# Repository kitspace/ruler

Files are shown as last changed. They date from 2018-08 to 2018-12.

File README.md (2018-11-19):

# Kitspace PCB Ruler

A PCB design reference ruler made using Inkscape, [svg2shenzhen](https://github.com/badgeek/svg2shenzhen/) and KiCad (v5). It's up [on Kitspace](https://kitspace.org/boards/github.com/monostable/ruler/) of course. You can [buy it on Tindie](https://www.tindie.com/products/kasbah/kitspace-pcb-ruler-2/) while stocks last.

- You can use it as a ruler and as a reference for footprint sizes when working on a PCB design.
- The front is a functioning circuit if you populate it. The LEDs will light up if you connect it via USB and press the buttons.
- There are also pads for testing LED polarity.
- It's in a panel to show off two different ways to attach designs within a panel: mouse-bites and v-score. These are indicated on the back as well.

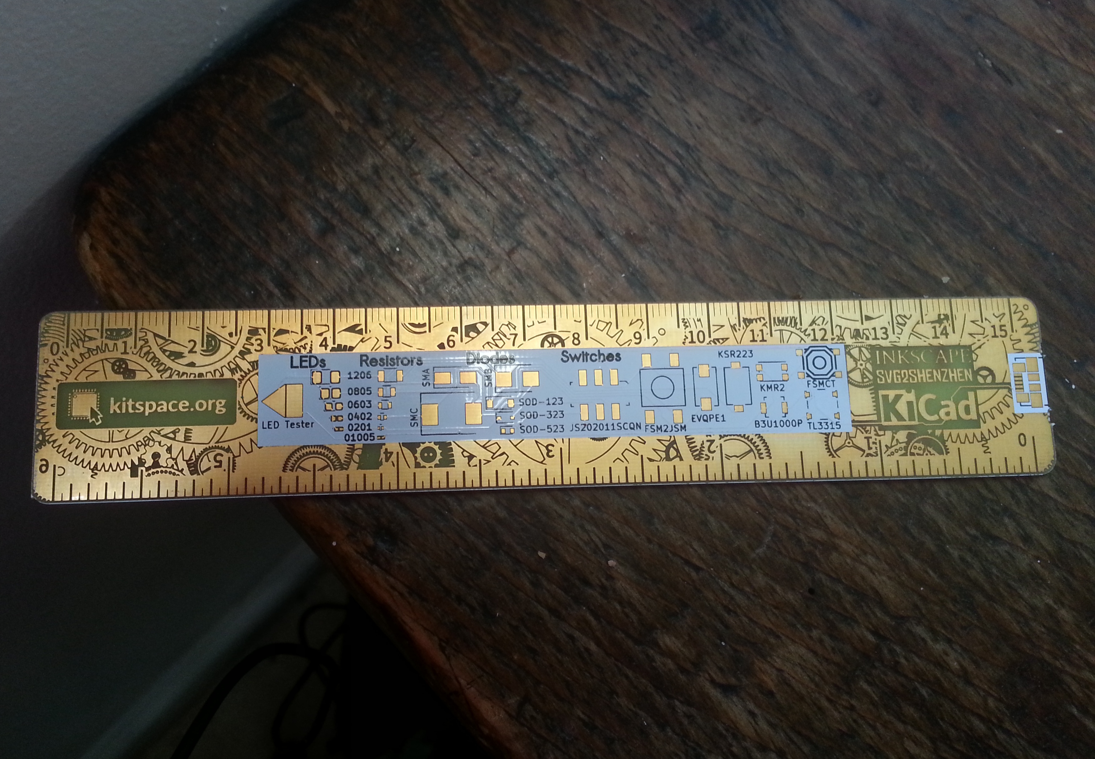
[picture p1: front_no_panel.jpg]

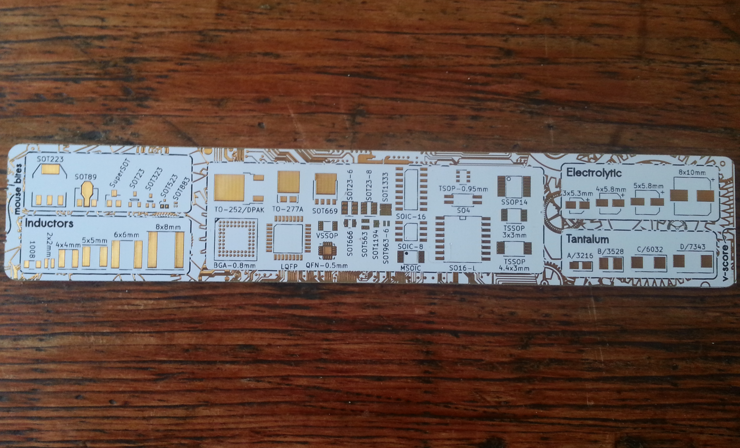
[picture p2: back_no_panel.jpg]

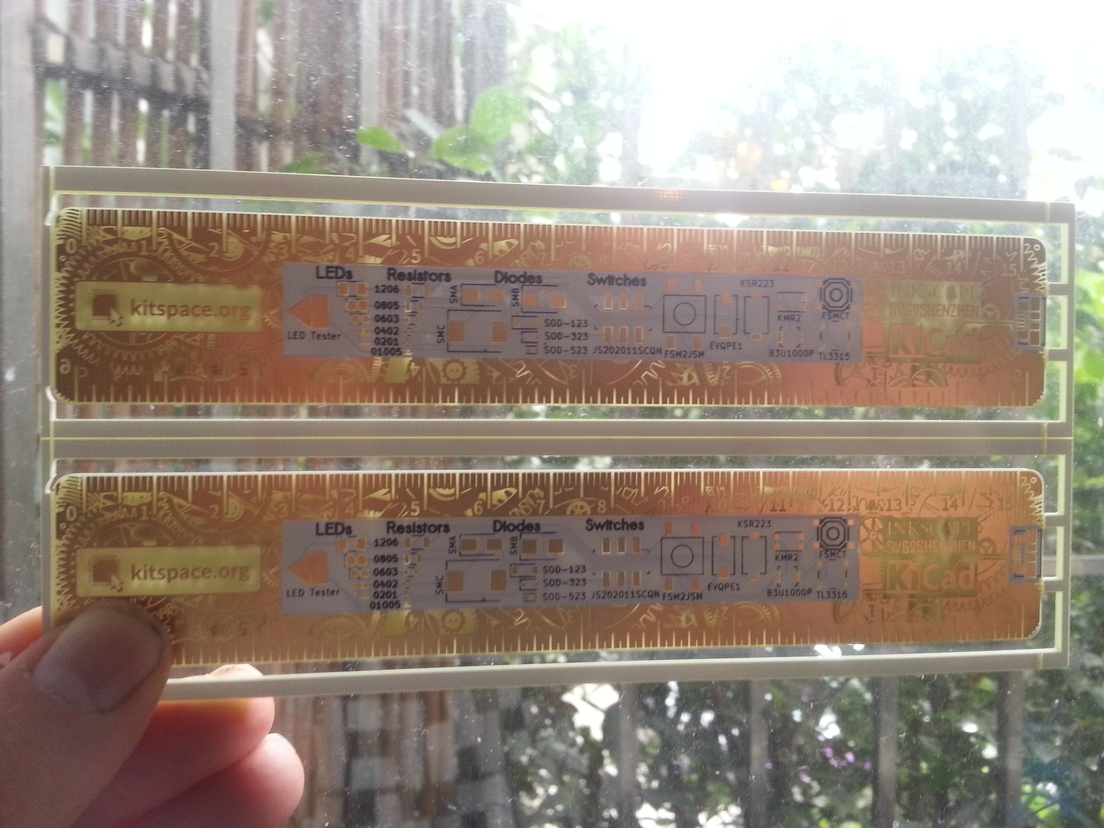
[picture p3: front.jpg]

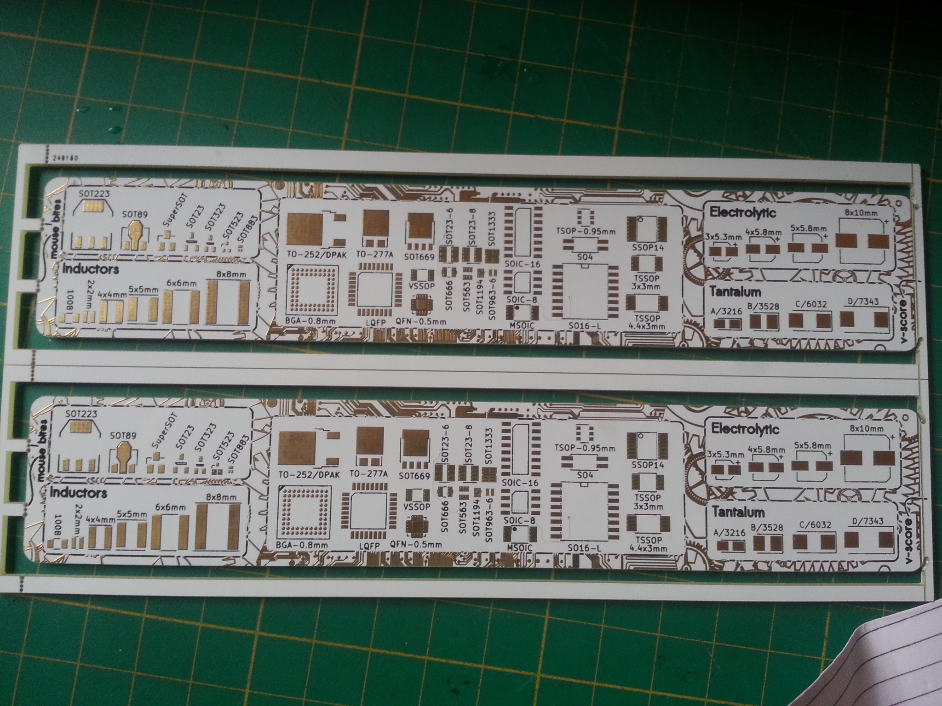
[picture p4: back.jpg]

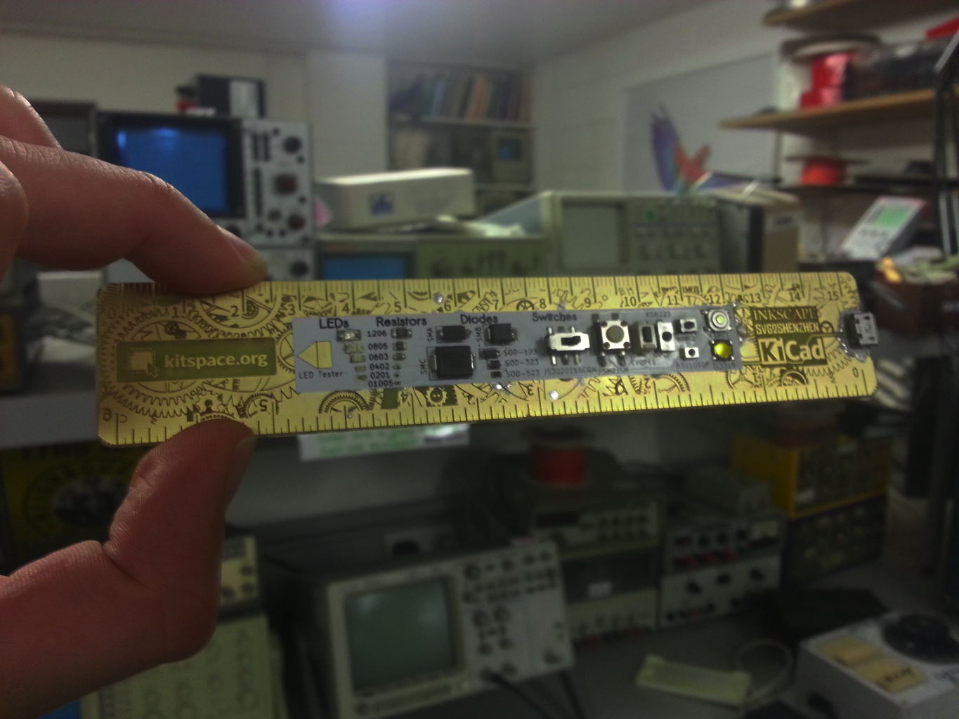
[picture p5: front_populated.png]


<iframe width="560" height="315" src="https://www.youtube.com/embed/yOuZpUTyYj4" frameborder="0" allow="accelerometer; autoplay; encrypted-media; gyroscope; picture-in-picture" allowfullscreen></iframe>

## License

<br />This work is licensed under a <a rel="license" href="http://creativecommons.org/licenses/by-sa/4.0/">Creative Commons Attribution-ShareAlike 4.0 International License</a>.

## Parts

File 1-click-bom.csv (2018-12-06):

References | Qty | Description | Manufacturer | MPN | Manufacturer | MPN | Manufacturer | MPN | Manufacturer | MPN | Manufacturer | MPN | Digikey | Mouser | RS | Newark | Farnell
D1 | 1 | SMA Diode | Bourns | SMAJ12A |  |  |  |  |  |  |  |  | SMAJ12ABCT-ND | 652SMAJ12A | 7673721P | 67R1525 | 1899443
D2 | 1 | SMB Diode | Littelfuse | SMBJ12A |  |  |  |  |  |  |  |  | SMBJ12ALFCT-ND | 576SMBJ12A | 7645574 | 72K7310 | 1827609
D3 | 1 | SMC Diode | Vishay | SMCJ15CA-E3/57T |  |  |  |  |  |  |  |  | SMCJ15CA-E3/57TGICT-ND | 625SMCJ15CAE3 | 5180741P | 10R0752 | 1698885
D4 | 1 | SOD-123 Diode | Diodes Inc. | SD101CW-7-F | Diodes Inc. | 1N5711W-7-F |  |  |  |  |  |  | 1N5711W-FDICT-ND | 6211N5711WF | 7512733 | 23T9766 | 1858640
D5 | 1 | SOD-323 Diode | Diodes Inc. | S5GC-13-F | MULTICOMP | S5GC-13-F |  |  |  |  |  |  | S5GC-FDICT-ND | 621S5GCF | 7514828 | 12T1408 | 2306338
D6 | 1 | SOD-523 Diode | Central Semiconductor | CMOZ1L8 TR | Bourns | CDSOD523-T05 | Bourns | CDSOD523-T05C | Central Semiconductor | CMOZ22L TR | Nexperia | BZX585-C2V7,115 | BZX585-C2V7,115-ND | 771BZX585C2V7115 |  | 32AC6814 | 2777512
J1 | 1 | USB micro B | Molex | 47346-0001 |  |  |  |  |  |  |  |  | WM17141CT-ND | 538473460001 | 7025475 | 96M8533 | 1568026
LED2 | 1 | led 0402 red | Lumex | SML-LX0402SIC-TR | Panasonic | LNJ247W82RA | Broadcom | HSMC-C280 |  |  |  |  | 516-3060-1-ND | 630HSMCC280 | 8676548P | 68Y1150 | 2494321
LED3 | 1 | LED 0603 red | Everlight | 19-217/R6C-AL1M2VY/3T | Broadcom | HSMH-C190 |  |  |  |  |  |  | 1080-1585-1-ND | 630HSMHC190 | 7166570P | 68Y1170 | 2497373
LED4 | 1 | LED 0805 red | Dialight | 597-3003-407F | Würth Elektronik | 150080RS75000 |  |  |  |  |  |  | 350-2947-1-ND | 710150080RS75000 | 419209 | 59M5865 | 1465992
LED5 | 1 | LED 1206 red | Dialight | 597-3111-402F | Würth Elektronik | 156120RS75000 | VCC | CMD15-21VRC/TR8 |  |  |  |  | 350-2880-ND | 710156120RS75000 | 8154278P | 93B3495 | 4600927
LED6 | 1 | led red 0.6mm 0.3mm | Kingbright | APG0603SURC-TT | Kingbright | APG0603SEC-E-TT |  |  |  |  |  |  | 754-2024-1-ND | 604APG0603SURCTT
R1 | 1 | resistor 1k 0201 | Vishay | CRCW02011K00FNED |  |  |  |  |  |  |  |  | 541-1.00KABCT-ND | 71CRCW02011K00FNED | 6649799 | 89M6577 | 2282179
R2 | 1 | 1k 0402 | Vishay | CRCW04021K00FKED | Yageo | RC0402JR-7W1KL | Susumu | RR0510P-102-D |  |  |  |  | 541-1.00KLCT-ND | 754RR0510P102D | 6788872 | 24W1850 | 2132441
R3 | 1 | 1k 0603 | Vishay | CRCW06031K00FKEA | Yageo | RC0603JR-7W1KL |  |  |  |  |  |  | 541-1.00KHCT-ND | 603RC0603JR7W1KL | 6789875 |  | 2132444
R4 | 1 | 1k 0805 | Vishay | CRCW08051K00FKEA |  |  |  |  |  |  |  |  | 541-1.00KCDKR-ND | 603RC0805JR7W1KL | 6790982 | 61M5425 | 2303550
R5 | 1 | 1k 1206 | Vishay | CRCW12061K00FKEA |  |  |  |  |  |  |  |  | 541-1.00KFDKR-ND | 603RC1206JR7W1KL | 6791844 | 61M5528 | 2307294
R6 | 1 | 1k 01005 | Vishay Dale | CRCW01001K00FREL | Panasonic | ERJ-XGNF1001Y |  |  |  |  |  |  | 541-4278-1-ND | 71CRCW01001K00FREL |  | 05X8735 | 2355575
SW1 | 1 | KMR2 | C&K Components | KMR211NG LFS | C&K Components | KMR231NG LFS |  |  |  |  |  |  | CKN10246CT-ND | 611KMR211NGLFS | 1359376 | 50AC5257 | 2845733
SW2 | 1 | EVQPE1 | Panasonic | EVQ-PE104K | Panasonic | EVQPE104K |  |  |  |  |  |  | P13593SCT-ND | 667EVQPE104K | 1250220P |  | 2459522
SW3 | 1 | B3U-1000P | Omron | B3U-1000P | Omron | B3U-1000P-B |  |  |  |  |  |  | SW1020CT-ND | 653B3U1000P | 419867 | 34M5296 | 1333654
SW4 | 1 | FSMCT | TE Connectivity / Alcoswitch | FSMCT | TE Connectivity / Alcoswitch | FSMCTATR | TE Connectivity / Alcoswitch | FSMCTA | TE Connectivity | 8-1437565-0 |  |  | 450-2133-1-ND | 506FSMCTTR | 1314775P | 95Y0178 | 2610939
SW5 | 1 | TL3315NF160Q | E-Switch | TL3315NF160Q |  |  |  |  |  |  |  |  | EG4621CT-ND | 612TL3315NF160Q |  | 15N4507 | 2103642
SW6 | 1 | FSM2JSM | TE Connectivity | FSM2JSMAATR |  |  |  |  |  |  |  |  | 450-1792-1-ND | 506FSM2JSMAATR | 7182474 | 14H0922 | 2667807
SW7 | 1 | JS202011SCQN | C&K Components | JS202011SCQN |  |  |  |  |  |  |  |  | 401-2002-1-ND | 611JS202011SCQN | 1546137 |  | 2320019
SW8 | 1 | KSR223 | C&K Components | KSR223G LFG |  |  |  |  |  |  |  |  | 401-1704-1-ND | 611KSR223GLFG |  | 95W3306 | 2320064

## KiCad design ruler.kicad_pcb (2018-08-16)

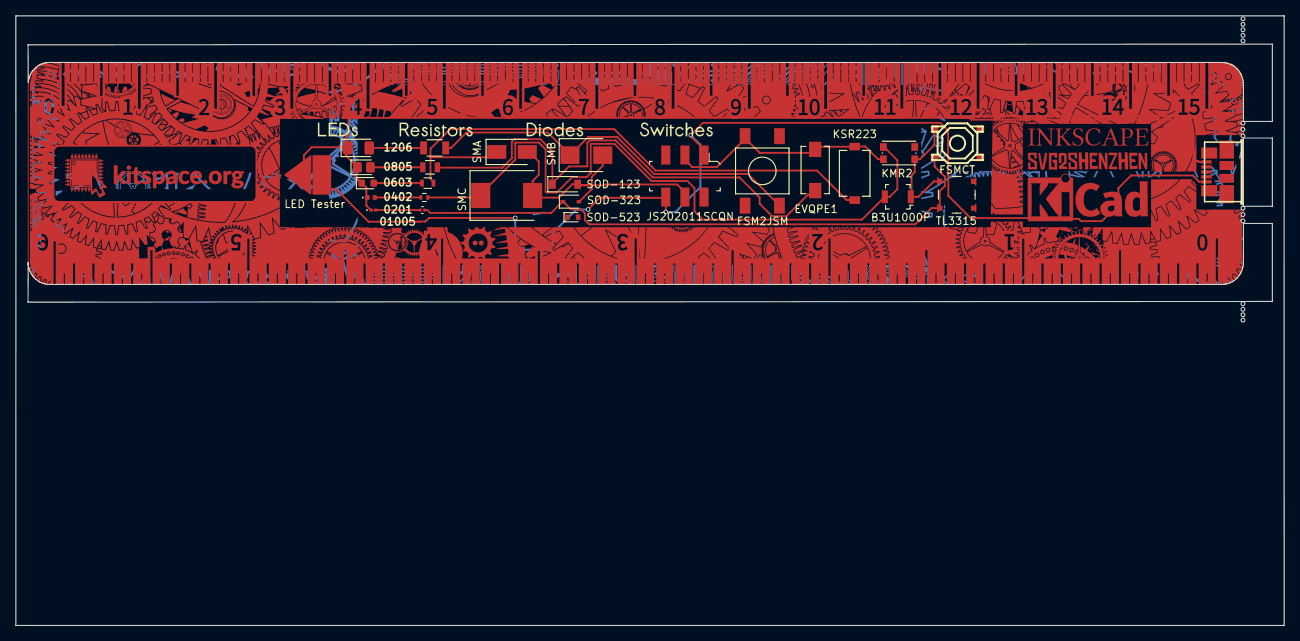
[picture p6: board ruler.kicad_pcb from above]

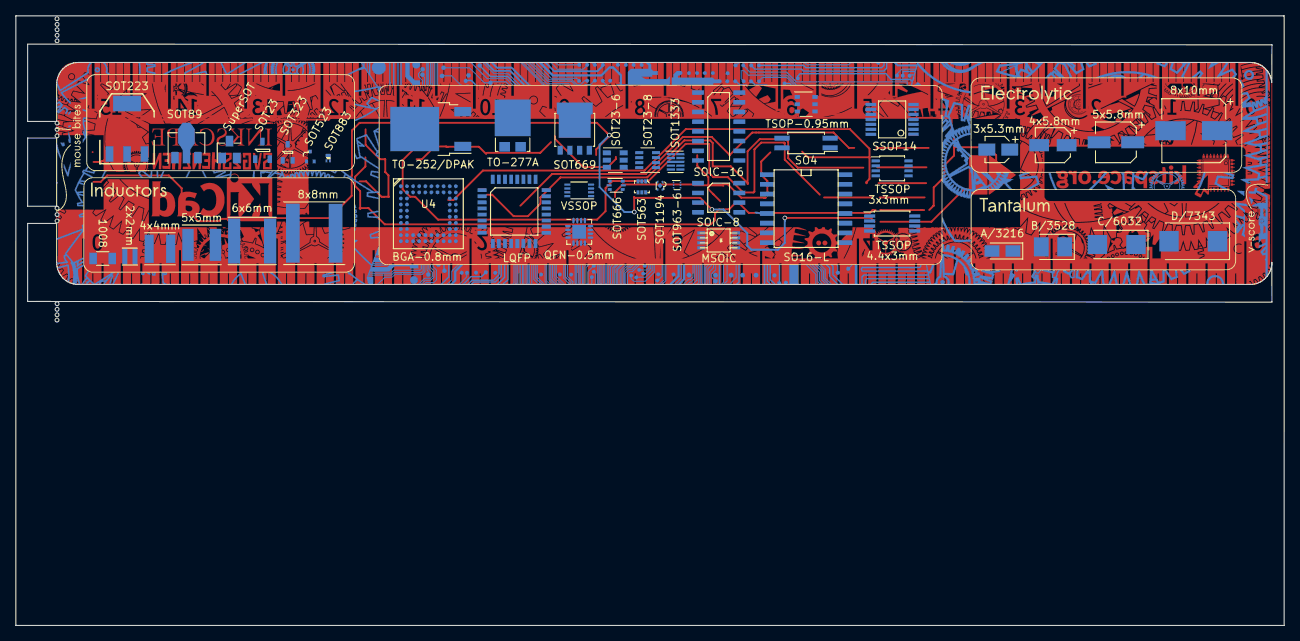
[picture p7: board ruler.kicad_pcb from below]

Board: 2 copper layers, 166.0 x 79.8 mm, 79 parts (47 on the bottom side), 15 nets.

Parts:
C1: 3x5.3mm; CP_Elec_3x5.3
C2: 4x5.8mm; CP_Elec_4x5.8
C3: 5x5.8mm; CP_Elec_5x5.8
C4: 8x10mm; CP_Elec_8x10
C5: A/3216; CP_Tantalum_Case-A_EIA-3216-18_Reflow
C6: B/3528; CP_Tantalum_Case-B_EIA-3528-21_Reflow
C7: C/6032; CP_Tantalum_Case-C_EIA-6032-28_Reflow
C8: D/7343; CP_Tantalum_Case-D_EIA-7343-31_Reflow
D1: SMA; D_SMA
D2: SMB; D_SMB
D3: SMC; D_SMC
D4: SOD-123; D_SOD-123
D5: SOD-323; D_SOD-323
D6: SOD-523; D_SOD-523
DRAWING1: Conn_01x01; ruler
DRAWING2: Conn_01x01; leds_text
DRAWING3: Conn_01x01; resistors_text
DRAWING4: Conn_01x01; diodes_text
DRAWING5: Conn_01x01; switches_text
DRAWING9: Conn_01x01; inductors_text
DRAWING10: Conn_01x01; tantalum_text
DRAWING11: Conn_01x01; electrolytic_text
J1: USB_OTG; conn_usb_B_micro_smd
L1: 1008; Inductor_1008
L2: 8x8mm; Inductor_Taiyo-Yuden_NR-80xx
L3: 4x4mm; Inductor_Taiyo-Yuden_MD-4040
L4: 5x5mm; Inductor_Taiyo-Yuden_MD-5050
L5: 6x6mm; Inductor_Taiyo-Yuden_NR-60xx
L6: 2x2mm; Inductor_Taiyo-Yuden_NR-20xx
LED1: LED Tester; led_test_pads
LED2: 0402; LED_0402_1005Metric
LED3: 0603; LED_0603_1608Metric
LED4: 0805; LED_0805_2012Metric
LED5: 1206; LED_1206_3216Metric
LED6: 0201; LED_0201_0603Metric
Q1: SOT23; SOT-23
Q2: SOT323; SOT-323
Q3: SOT883; SOT-883-B
Q4: SOT523; SOT-523
Q5: SOT223; SOT223_GND_VO_VI
Q6: SOT89; SOT-89-3
Q7: SuperSOT; SuperSOT-3
R1: 1k; R_0201
R2: 1k; R_0402
R3: 1k; R_0603
R4: 1k; R_0805
R5: 1k; R_1206
R6: 1k; R_01005_0402Metric
SW1: KMR2; SW_SPST_KMR2
SW2: EVQPE1; SW_SPST_EVQPE1
SW3: B3U1000P; Switch_Tactile_SMD_B3U-1000P
SW4: FSMCT
SW5: TL3315; Switch_4.5x4.5mm_SMD_TL3315NF160Q
SW6: FSM2JSM; FSM2JSMA
SW7: JS202011SCQN; Switch_Slide_JS202011SCQN
SW8: KSR223; KSR
U1: QFN-0.5mm; QFN-16-1EP_3x3mm_Pitch0.5mm
U2: LQFP; LQFP-32
U3: SOIC-8
U4: BGA-0.8mm; BGA-64-0.8mm
U5: TSSOP; TSSOP-8_3x3mm_Pitch0.65mm
U6: MSOIC; msoic-8
U7: TSOP-0.95mm; TSOP-6_1.65x3.05mm_Pitch0.95mm
U8: SOT23-6; SOT-23-6
U9: SOT23-8; SOT-23-8
U10: SOT963-6; SOT-963
U11: SSOP14; SSOP-14
U12: SO16-L; SO-16-L
U13: SOT666; SOT-666
U14: SOT1194; SOT-1194-1
U15: SOT1333; SOT-1333-1
U16: SOT669; SOT-669_LFPAK
U17: TSSOP; TSSOP-8_4.4x3mm_Pitch0.65mm
U18: SO4; SO-4_4.4x2.3mm_Pitch1.27mm
U19: VSSOP; VSSOP-8_2.3x2mm_Pitch0.5mm
U20: TO-252/DPAK; TO-252-2
U21: TO-277A
U22: SOIC-16
U23: SOT563; SOT-563

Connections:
+5V: J1.1, R6.1, SW7.1, SW7.6
GND: J1.5, LED1.1, LED2.1, LED3.1, LED4.1, LED5.1, LED6.1
LED_V+: D1.2, D2.2, D3.2, D4.2, D5.2, SW7.5
unnamed: D1.1, R3.1, SW8.2
unnamed: D2.1, R5.1, SW6.2
unnamed: D3.1, R2.1, SW1.2, SW3.2
unnamed: D4.1, R4.1, SW2.2
unnamed: D5.1, R1.1, SW4.1, SW4.2, SW5.1, SW5.2
unnamed: LED1.2, R6.2
unnamed: LED2.2, R2.2
unnamed: LED3.2, R3.2
unnamed: LED4.2, R4.2
unnamed: LED5.2, R5.2
unnamed: LED6.2, R1.2
SW_V+: SW1.1, SW2.1, SW3.1, SW4.3, SW4.4, SW5.3, SW5.4, SW6.1, SW7.2, SW8.1

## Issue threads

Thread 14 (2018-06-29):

PCB is not a functioning circuit

kasbah, 2018-06-29:
The traces at the bottom went missing, the vias at the top went missing   :confused: . In waaaaay too much of rush when I sent this off.

badgeek, 2018-06-30:
so many open issues 😕 ... as this is the first pcb manufactured using svg2shenzhen, are there any specific svg2shenzhen related bug ?

kasbah, 2018-06-30:
Ha no, svg2shenzhen is working great! Zones would useful but we know that. Well, one smaller thing maybe: would be good to make all the drawing "reference" and "value" texts invisible by default. I'll probably take a look at doing that soon.

But mainly I just _really_ rushed it to try and have something to hand out at the Hackaday Belgrade conference (but it still didn't arrive on time in the end :rage:).

Closed 2018-11-01.

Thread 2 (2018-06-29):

Bottom PCB, LED and resistor size text is missing

kasbah, 2018-06-29:

Closed 2018-11-01.

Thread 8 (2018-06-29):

Text is too close to other silkscreen in a number of places on back

kasbah, 2018-06-29:

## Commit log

2018-04-12 Extend ruler, use rounded edges, sort out numbers
    [pcbart.kicad_pcb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]
2018-04-12 Add url and logo
    [pcbart.kicad_pcb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]
2018-04-13 Adjust logo
    [pcbart.kicad_pcb]
2018-04-13 Move inches to front bottom
    [pcbart.kicad_pcb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]
2018-04-13 Experiment with slikscreen logo
    [pcbart.kicad_pcb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]
2018-04-13 More silkscreen, switch to svg2shenzhen dev vers.
    [pcbart.kicad_pcb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]
2018-04-19 Adjust stuff
    [pcbart.kicad_pcb]
2018-04-19 Switch to using kicad_mod for pcb art
    [pcbart.kicad_pcb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]
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2018-05-08 Clear out old stuff, include drawing as module
    [ruler.kicad_pcb, ruler.sch]
2018-05-08 Add some push-buttons and LEDs to schematic
    [ruler.sch]
2018-05-08 Do some layouting
    [ruler.kicad_pcb, ruler.sch]
2018-05-08 Add more push-buttons
    [ruler.kicad_pcb, ruler.sch]
2018-05-08 Re-enable switching individual LEDs on
    [ruler.sch]
2018-05-08 Add bigger resistors
    [ruler.kicad_pcb, ruler.sch]
2018-05-08 Add diodes
    [ruler.kicad_pcb, ruler.sch]
2018-05-09 Adjust mouse-bites to accommodate USB connector
    [ruler.kicad_pcb]
2018-05-09 Re-arrange push-button connections
    [ruler.kicad_pcb, ruler.sch]
2018-05-09 Re-arrange and replace some switches
    [ruler.kicad_pcb, ruler.sch]
2018-05-09 Adjust led test pads
    [ruler.kicad_pcb, ruler.sch]
2018-05-09 Route route route
    [ruler.kicad_pcb, ruler.sch]
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2018-05-09 Add 1/20 inch markers
    [ruler.kicad_pcb]
2018-05-09 Add inductors, caps, transitors and ICs
    [ruler.kicad_pcb, ruler.sch]
2018-05-09 Change text to inkscape versions
    [ruler.kicad_pcb, ruler.sch]
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2018-05-09 Adjust led tester text
    [ruler.kicad_pcb, ruler.sch]
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2018-05-10 Add drawings, ants etc
    [ruler.kicad_pcb, ruler.sch]
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2018-05-20 A lot of changes
    [ruler-B.Cu.gbr, ruler-B.Mask.gbr, ruler-B.SilkS.gbr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]
2018-05-20 Adjust mouse-bite drills and plot
    [ruler-B.Cu.gbr, ruler-B.Mask.gbr, ruler-B.SilkS.gbr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]
2018-05-21 Adjust bottom separator graphics
    [ruler-B.Cu.gbr, ruler-B.Mask.gbr, ruler-B.SilkS.gbr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]
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2018-05-21 Make adjustements for AllPCB panelization
    [ruler-B.Cu.gbr, ruler-B.Mask.gbr, ruler-B.SilkS.gbr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]
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2018-06-30 Remove second copy for now, remove all tracks
    [ruler.kicad_pcb]
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2018-07-13 Use gears as background for the logos
    [ruler.kicad_pcb]
2018-07-13 Sort out usb pads and connections
    [ruler.kicad_pcb]
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2018-07-13 Give back Cu a nice background
    [ruler.kicad_pcb]
2018-07-13 Work on back layout and graphics
    [ruler.kicad_pcb]
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2018-07-26 Put copper around inch numbers and marks
    [ruler.kicad_pcb]
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2018-08-12 Re-save schematic with kicad 4
    [ruler.sch]
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2018-08-12 Convert to kicad-5 properly?
    [ruler.kicad_pcb, ruler.sch]
2018-08-12 Add a tactile switch and 0201 LED
    [ruler.kicad_pcb, ruler.sch]
2018-08-12 Move some stuff around and plot
    [ruler-B.Cu.gbr, ruler-B.Mask.gbr, ruler-B.SilkS.gbr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]
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2018-08-13 Fix power track
    [ruler-B.Cu.gbr, ruler-B.Mask.gbr, ruler-B.SilkS.gbr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]
2018-08-13 Fix text line width for a sot
    [ruler-B.Cu.gbr, ruler-B.Mask.gbr, ruler-B.SilkS.gbr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]
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2018-08-13 Flip the inch markers
    fixes #15
    [ruler-B.Cu.gbr, ruler-B.Mask.gbr, ruler-B.SilkS.gbr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]
2018-08-13 Add a v-score between rulers
    fixes #12
    [ruler-B.Cu.gbr, ruler-B.Mask.gbr, ruler-B.SilkS.gbr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]
2018-08-13 Make v-score pointer line thinner
    [ruler-B.Cu.gbr, ruler-B.Mask.gbr, ruler-B.SilkS.gbr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]
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2018-08-13 Switch out second b3u button
    [ruler-B.Cu.gbr, ruler-B.Mask.gbr, ruler-B.SilkS.gbr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]
2018-08-13 Add some drills, remove some drawings
    [ruler-B.Cu.gbr, ruler-B.Mask.gbr, ruler-B.SilkS.gbr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]
2018-08-13 Duplicate the layout into the frame
    [ruler-B.Cu.gbr, ruler-B.Mask.gbr, ruler-B.SilkS.gbr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]
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2018-08-14 Adjust b3u button text
    [ruler-B.Cu.gbr, ruler-B.Mask.gbr, ruler-B.SilkS.gbr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]
2018-08-14 Improve part selection for mouser
    [1-click-bom.tsv]
2018-08-16 Remove trace crossing 4 on the ruler marks
    [ruler-B.Cu.gbr, ruler-B.Mask.gbr, ruler-B.SilkS.gbr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]
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2018-08-16 Route buttons, clean up
    [ruler-B.Cu.gbr, ruler-B.Mask.gbr, ruler-B.SilkS.gbr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]
2018-08-16 Adjust traces a bit
    [ruler-B.Cu.gbr, ruler-B.Mask.gbr, ruler-B.SilkS.gbr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]
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2018-08-16 Add more footprints on back
    [ruler-B.Cu.gbr, ruler-B.Mask.gbr, ruler-B.SilkS.gbr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]
2018-08-16 More footprints on back
    [ruler-B.Cu.gbr, ruler-B.Mask.gbr, ruler-B.SilkS.gbr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]
2018-08-16 Use newer kicad LED footprints, adjust buttons
    [ruler-B.Cu.gbr, ruler-B.Mask.gbr, ruler-B.SilkS.gbr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]
2018-08-16 Clean up tracks a bit
    [ruler-B.Cu.gbr, ruler-B.Mask.gbr, ruler-B.SilkS.gbr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]
2018-08-16 Add 0s to ruler markings
    [ruler-B.Cu.gbr, ruler-B.Mask.gbr, ruler-B.SilkS.gbr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]
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2018-08-16 Duplicate circuit and adjust placement
    [ruler-B.Cu.gbr, ruler-B.Mask.gbr, ruler-B.SilkS.gbr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]
2018-08-16 Increase text size for v-score and mouse-bites
    [ruler-B.Cu.gbr, ruler-B.Mask.gbr, ruler-B.SilkS.gbr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]
2018-08-17 Reduce inkscape export dpi to 1000
    [ruler-B.Cu.gbr, ruler-B.Mask.gbr, ruler-B.SilkS.gbr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]
2018-08-20 Increase line thickness and reduce DPI
    [ruler-B.Cu.gbr, ruler-B.Mask.gbr, ruler-B.SilkS.gbr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]
2018-12-06 Fix SMC diode selection in BOM
    [1-click-bom.csv, 1-click-bom.tsv]
2019-12-17 Remove gerbers for kitspace test
    [ruler-B.Cu.gbr, ruler-B.Mask.gbr, ruler-B.SilkS.gbr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]
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2024-05-24 Update design to de-clutter bottom side
    [ruler-B_Cu.gbr, ruler-B_Mask.gbr, ruler-B_Silkscreen.gbr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]
2024-05-24 Add 1/10 inch marker
    [ruler-B_Cu.gbr, ruler-B_Mask.gbr, ruler-B_Silkscreen.gbr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]
2024-05-25 Increase v-score rail width
    [ruler-B_Cu.gbr, ruler-B_Mask.gbr, ruler-B_SilkS.gbr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]
